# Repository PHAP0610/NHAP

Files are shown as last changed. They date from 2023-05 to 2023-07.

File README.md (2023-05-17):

# STM32F103

## Hardware BOARD V0.1

All file include and source in this: https://github.com/nguyentrungthao/STM32/tree/dev

### Module 7 segment with two ic 74595
1. Pin configuration.

<!-- cách ra 1 dòng để git hiểu là xuống hàng -->
<!-- :--- là căn trái :---: là căn giữa ---: là căn phải trong cột -->
| STM32 | 74595  | 
| :---: | :---: |
| PA4 | SER |
| PA5 | OE |
| PA6 | RCLK |
| PA7 | SRCLK |

2. Code 

high 8-bit to select a 7-segment digit 
low 8-bit is code-7-segment 
code7segment is used in this board sequence:
<!--  có nhiều fotmat khác như c, cpp, js, html,...... -->
```c
/* this code only use for this version board */
const char code7seg[] = {0xD7, 0x14, 0xCD, 0x5D, 0x1E, 0x5B, 0xDB, 0x15, 0xDF, 0x5F};
```
### Module rotary encoder 
1. Pin configuration 

| STM32 | Rotary Encoder | description | 
| :---: | :---: | :--- |
| PA8 | channel A | pull up |
| PA9 | channel B | pull up |
| PA10 | buttuon | pull up |

2. Code

PA8 - PA9 is encoder mode of timer1 
```c
/* Enable TIM1 encoder mode */
/* USER CODE BEGIN 2 */
HAL_TIM_Encoder_Start_IT(&htim1, TIM_CHANNEL_ALL);
/* USER CODE END 2 */

/* Get encoder value */
encoderValue = __HAL_TIM_GetCounter(&htim1);
```

### AC voltage control
1. Pin configuration 

| STM32 | Module | description |
| :---: | :---: | :--- |
| PB0 | AC Detec| pull up |
| PB1 | Triac |  |

2. code 

PB0 should be an EXT pin 
``` c
/* proccess when interrupt */
void HAL_GPIO_EXTI_Callback(uint16_t GPIO_Pin){
	if(GPIO_Pin == ACDET_Pin){
		SETFLAG(FLAG_ACDET_TRIGGER, flag);
        // control angle to set triac base on time which is calculated by PID
		__HAL_TIM_SET_COUNTER(&htim4, (uint16_t)(triac.giaTriDieuKhien * 1000));
//		__HAL_TIM_SET_COUNTER(&htim4, 9000);
	}
}
```

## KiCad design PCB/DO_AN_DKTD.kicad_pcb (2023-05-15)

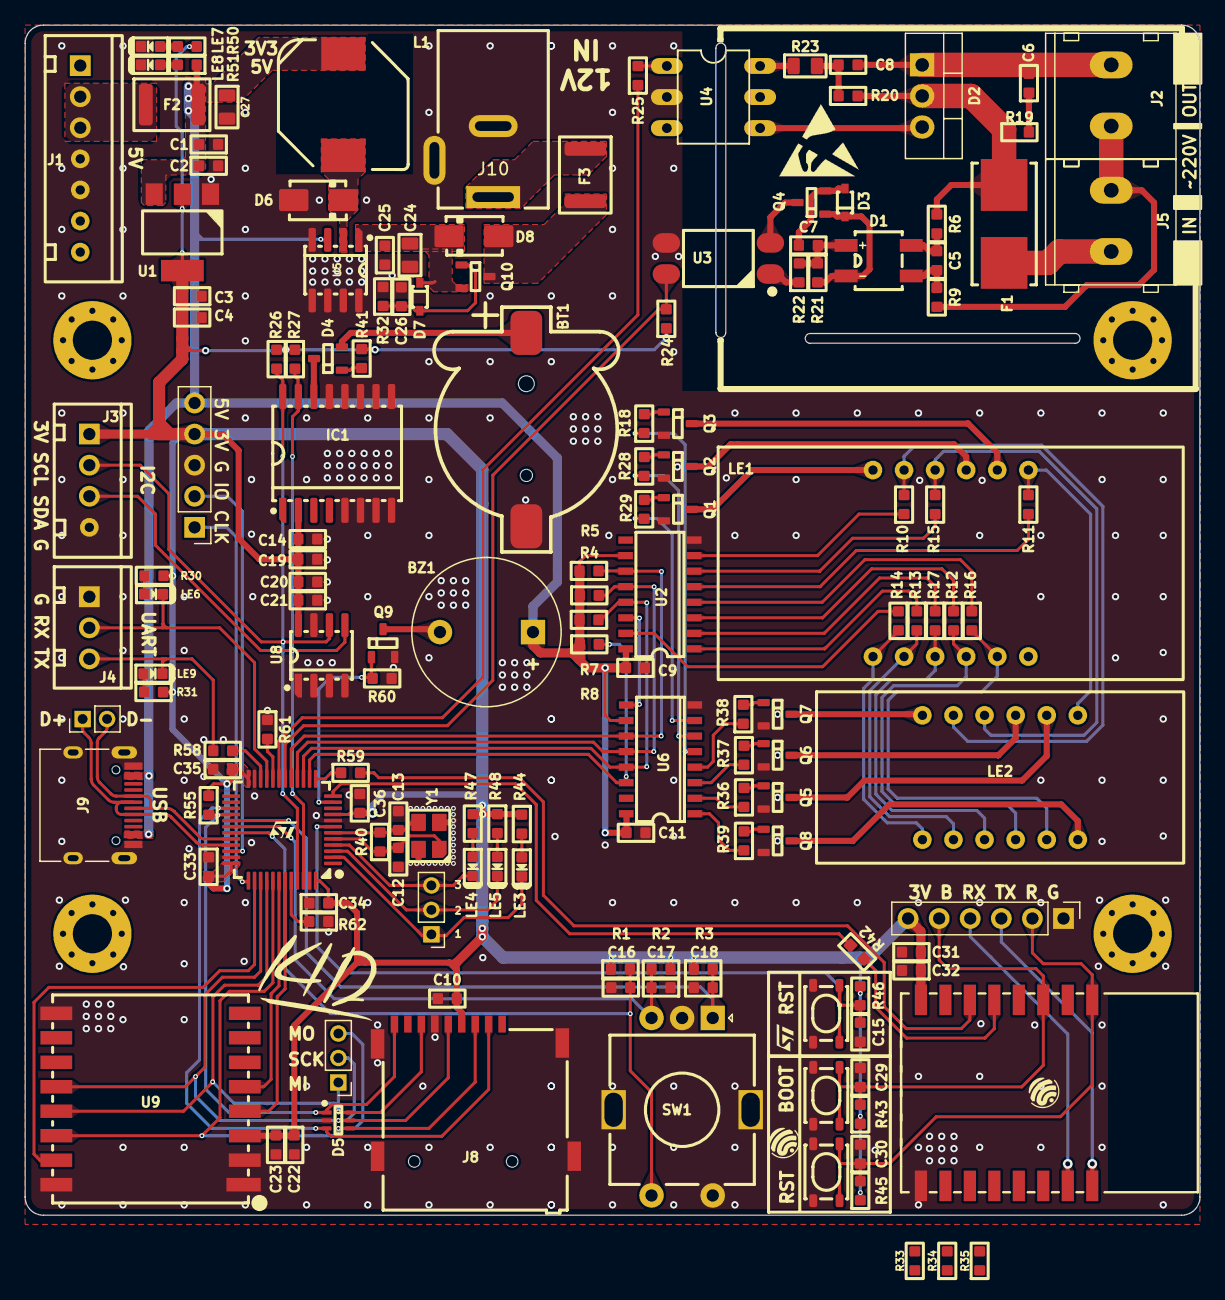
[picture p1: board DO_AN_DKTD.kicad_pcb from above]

Board: 2 copper layers, 96.0 x 97.2 mm, 153 parts (0 on the bottom side), 120 nets.

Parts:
BT1: CR1220; BatteryHolder_CR1220
BZ1: Buzzer; Buzzer_12x9.5RM7.6
C1, C3, C15, C16, C17, C18, C22, C25, C29, C30, C31: 1uF; C_0603
C2, C4, C9, C10, C11, C19, C21, C23, C26, C32, C33, C34, C35, C36: 100nF; C_0603
C5, C6: 10nF; C_0603
C7, C14, C20: 10uF; C_0603
C8: 50nF; C_0603
C12, C13: 22pF; C_0603
C24, C27: 10uF; C_0805
D1: MB10F; Bridge_MB10F-13
D2: TRIAC; TO-220-3_Vertical
D3: 1N4148; D_SOD323
D4: BAT54C; SOT23-3
D5: SMF05C; TSSOP-6
D6, D8: SS54; D_SMA
D7: D_Schottky; D_SOD323
F1: Fuse; Fuseholder_Littelfuse_Nano2_154x
F2, F3: Fuse; Fuse_1812_4532Metric
IC1: RTC_DS3231M; SOIC-16W_7.5x10.3mm_P1.27mm
J1: Conn_01x07; Conn_XH-P2.54mm-7P
J2, J5: Conn_01x02; KF128-5.0-2P
J3: Conn_01x04; Conn_XH-P2.54mm-4P
J4: Conn_01x03; Conn_XH-P2.54mm-3P
J6: PinHeader_1x06_P2.54mm_Vertical
J7: Conn_01x05_Male; PinHeader_1x05_P2.54mm_Vertical
J8: Micro_SD_Card_Det1; MicroSD_Socket_9P
J9: USB_C_Receptacle; USB_C_Receptacle_XKB_U262-16XN-4BVC11
J10: Jack-DC; BarrelJack_Wuerth_6941xx301002
J11, J12: Conn_01x03_Pin; PinHeader_1x03_P2.00mm_Vertical
J13: Conn_01x02_Pin; PinHeader_1x02_P2.00mm_Vertical
L1: 68uH 2A; L_10.4x10.4_H4.8
LE1: 5631AS; 7Segment_4led_CC_38x19
LE2: 5631AS; 7Segment_4led_Cathode_30x14mm
LE3, LE4, LE5, LE6, LE7, LE8, LE9: Led; LED_0603
Q1, Q2, Q3, Q4, Q5, Q6, Q7, Q8: NPN; SOT23-3
Q9: N_Mosfet; SOT23-3
Q10: P_Mosfet; SOT23-3
R1, R2, R3, R4, R5, R7, R8, R26, R27, R55: 4k7; R_0603
R6, R9: 180k; R_0603
R10, R11, R12, R13, R14, R15, R16, R17, R22, R24, R30, R31, R41, R44, R47, R48, R50, R51: 1k; R_0603
R18, R28, R29, R36, R37, R38, R39: 2k; R_0603
R19: 39; R_0603
R20: 470; R_0603
R21: 22k; R_0603
R23: 360; R_0805
R25: 360; R_0603
R32: 12k; R_0603
R33, R34, R35, R43, R45, R46: 10k; R_0603
R40, R60: 1M; R_0603
R42: 100; R_0603
R58, R59: 100R; R_0603
R61, R62: 10K; R_0603
SW1: RotaryEncoder_Switch; RotaryEncoder_Alps_EC11E-Switch_Vertical_H20mm
SW2, SW3, SW4: SW_Push; SW_SPST_PTS810
U1: AMS1117; SOT233
U2, U6: 74HC595; SOIC-16W_3.92x10.2mm
U3: PC817; OPTO_SOT254P975X400-4N
U4: MOC3020M; DIL06-E
U5: XL1509; SOIC-8_3.9x4.9mm_P1.27mm
U7: STM32F103C8Tx; LQFP-48_7x7mm_P0.5mm
U8: 24C32N; SOIC-8_3.9x4.9mm_P1.27mm
U9: Ai-Thinker-Ra-02; MODULE_RA-02_LORA
U10: ESP-07; ESP8266-07__ESP32-C3-12F
Y1: Crystal_GND24_Small; Crystal_3225_4P_3.2x2.6mm

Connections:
+3V3: C3.2, C4.1, C10.2, C14.2, C19.2, C20.2, C21.2, C22.1, C23.1, C31.1, C32.1, C33.2, C34.2, C35.2, C36.2, IC1.2 (VCC), J3.1, J6.6, J7.4, J8.4 (VDD), R1.1, R2.1, R3.1, R24.1, R26.1, R27.1, R30.1, R31.1, R33.2, R34.2, R41.1, R43.1, R44.1, R45.1, R46.1, R47.1, R48.1, R50.1, R55.1, U1.2 (VO), U7.9 (VDDA), U7.24 (VDD), U7.36 (VDD), U7.48 (VDD), U8.8 (VCC), U9.3 (VDD), U10.8 (VCC)
+5V: BZ1.1 (-), C1.2, C2.1, C9.2, C11.2, C27.1, F2.2, J7.5, J9.A4 (VBUS), J9.A9 (VBUS), J9.B4 (VBUS), J9.B9 (VBUS), L1.2, R4.1, R5.1, R7.1, R8.1, R51.1, U1.3 (VI), U2.10 (~SRCLR), U2.16 (VCC), U5.3 (FB), U6.10 (~SRCLR), U6.16 (VCC)
/ESP/BOOT: C29.1, J6.5, R43.2, SW3.2, U10.18 (GPIO0)
/ESP/RST: C30.1, J6.2, R45.2, SW2.2, U10.1 (~RST)
/ESP/RX: J6.4, U10.21 (GPIO3/RXD)
/ESP/RX_ESP32: R42.2, U7.12 (PA2)
/ESP/TX: J6.3, U10.22 (GPIO1/TXD)
/ESP/TX_ESP32: R59.2, U10.6 (GPIO12)
/POWER/5vin: F2.1, J1.2, J1.3
/POWER/A: F3.1, J10.1
/POWER/B: D8.1, F3.2, Q10.3 (D)
/POWER/VOUT: D6.2, L1.1, U5.2 (OUTPUT)
/Peripheral/24C32.SCL: IC1.16 (SCL), J3.2, R26.2, U7.45 (PB8), U8.6 (SCL)
/Peripheral/24C32.SDA: IC1.15 (SDA), J3.3, R27.2, U7.46 (PB9), U8.5 (SDA)
/Peripheral/74HC595.OE: R7.2, U2.13 (~OE), U6.13 (~OE), U7.15 (PA5)
/Peripheral/74HC595.RCLK: R4.2, U2.12 (RCLK), U6.12 (RCLK), U7.16 (PA6)
/Peripheral/74HC595.SER: R8.2, U6.14 (SER), U7.14 (PA4)
/Peripheral/74HC595.SRCLK: R5.2, U2.11 (SRCLK), U6.11 (SRCLK), U7.17 (PA7)
/Peripheral/AC_DET: R24.2, U3.4, U7.18 (PB0)
/Peripheral/Buzzer: Q9.1 (G), R60.1, U7.11 (PA1)
/Peripheral/Encoder.EnC_A: C18.2, R3.2, SW1.A, U7.29 (PA8)
/Peripheral/Encoder.EnC_B: C17.2, R2.2, SW1.B, U7.30 (PA9)
/Peripheral/Encoder.EnC_BT: C16.2, R1.2, SW1.S1, U7.31 (PA10)
/Peripheral/L: F1.2, J5.1
/Peripheral/LE1: R29.1, U6.7 (QH)
/Peripheral/LE2: R28.1, U6.6 (QG)
/Peripheral/LE3: R18.1, U6.5 (QF)
/Peripheral/LE4: R38.1, U6.4 (QE)
/Peripheral/LE5: R37.1, U6.3 (QD)
/Peripheral/LE6: R36.1, U6.2 (QC)
/Peripheral/LE7: R39.1, U6.1 (QB)
/Peripheral/LOG_RX: J4.2, LE6.2, U7.21 (PB10)
/Peripheral/LOG_TX: J4.3, LE9.2, R58.1
/Peripheral/LORA.CS: U7.38 (PA15), U9.15 (~NSS)
/Peripheral/LORA.INT: U7.42 (PB6), U9.5 (DIO0)
/Peripheral/LORA.MISO: D5.6, J8.7 (DAT0), J12.1, U7.40 (PB4), U9.13 (MISO)
/Peripheral/LORA.MOSI: D5.4, J8.3 (CMD), J12.3, U7.41 (PB5), U9.14 (MOSI)
/Peripheral/LORA.RST: U7.43 (PB7), U9.4 (~RESET)
/Peripheral/LORA.SCK: D5.5, J8.5 (CLK), J12.2, U7.39 (PB3), U9.12 (SCK)
/Peripheral/L_after: D2.2 (A2), F1.1, R6.2, R19.1, R20.2
/Peripheral/Load: C6.2, C8.2, D2.1 (A1), J2.2
/Peripheral/N: J2.1, J5.2, R9.2
/Peripheral/SD.CS: D5.3, J8.2 (DAT3/CD), U7.27 (PB14)
/Peripheral/SD.DET: D5.1, J8.9 (DET), R55.2, U7.28 (PB15)
/Peripheral/TRIAC: R25.1, U7.19 (PB1)
/Peripheral/TYPE_C.D+: J9.A6 (D+), J9.B6 (D+), J13.1, U7.33 (PA12)
/Peripheral/TYPE_C.D-: J9.A7 (D-), J9.B7 (D-), J13.2, U7.32 (PA11)
/Peripheral/Vbat: BT1.1 (+), D4.2
/STM32/Led_test1: J11.1, LE3.2, U7.2 (PC13)
/STM32/Led_test2: J11.2, LE5.2, U7.3 (PC14)
/STM32/Led_test3: J11.3, LE4.2, U7.4 (PC15)
/STM32/PD0: C12.2, R40.1, U7.5 (PD0), Y1.1
/STM32/PD1: C13.1, R40.2, U7.6 (PD1), Y1.3
/STM32/RST: C15.1, R46.2, SW4.2, U7.7 (NRST)
/STM32/SWCLK: J7.1, U7.37 (PA14)
/STM32/SWDIO: J7.2, U7.34 (PA13)
GND: BT1.2 (-), C1.1, C2.2, C3.1, C4.2, C9.1, C10.1, C11.1, C12.1, C13.2, C14.1, C15.2, C16.1, C17.1, C18.1, C19.1, C20.1, C21.1, C22.2, C23.2, C24.2, C25.1, C26.2, C27.2, C29.2, C30.2, C31.2, C32.2, C33.1, C34.1, C35.1, C36.1, D5.2, D6.1, IC1.5 (GND), IC1.6 (GND), IC1.7 (GND), IC1.8 (GND), IC1.9 (GND), IC1.10 (GND), IC1.11 (GND), IC1.12 (GND), IC1.13 (GND), J1.4, J1.5, J3.4, J4.1, J6.1, J7.3, J8.6 (VSS), J8.10 (SHIELD), J9.A1 (GND), J9.A12 (GND), J9.B1 (GND), J9.B12 (GND), J9.S1 (SHIELD), J10.2, LE7.2, LE8.2, Q1.2 (E), Q2.2 (E), Q3.2 (E), Q5.2 (E), Q6.2 (E), Q7.2 (E), Q8.2 (E), Q9.2 (S), R32.2, R35.1, R60.2, R61.1, R62.1, SW1.C, SW1.MP (Shield), SW1.S2, SW2.1, SW3.1, SW4.1, U1.1 (GND), U2.8 (GND), U3.3, U4.2, U5.4 (ON/OFF), U5.5 (GND), U5.6 (GND), U5.7 (GND), U5.8 (GND), U6.8 (GND), U7.8 (VSSA), U7.23 (VSS), U7.35 (VSS), U7.47 (VSS), U8.1 (A0), U8.2 (A1), U8.3 (A2), U8.4 (GND), U8.7 (WP), U9.1 (GND), U9.2 (GND), U9.9 (GND), U9.16 (GND), U10.15 (GND), Y1.2, Y1.4
unnamed: D4.3, IC1.14 (VBAT)
unnamed: BZ1.2 (+), Q9.3 (D)
unnamed: C5.1, D1.4, R6.1
unnamed: C5.2, D1.2, R9.1
unnamed: C6.1, R19.2
unnamed: C8.1, R20.1, R23.2
unnamed: C7.1, D1.1 (+), R21.1, R22.2
unnamed: D1.3 (-), D3.2, Q4.1 (B), R21.2
unnamed: D2.3 (G), U4.4
unnamed: D4.1, R41.2
unnamed: LE1.12 (CC1), Q1.3 (C)
unnamed: LE1.9 (CC2), Q2.3 (C)
unnamed: LE1.8 (CC3), Q3.3 (C)
unnamed: LE1.3 (DPX), LE2.3 (DPX), R17.2
unnamed: LE1.11 (a), LE2.11 (a), R10.2
unnamed: LE1.7 (b), LE2.7 (b), R11.2
unnamed: LE1.4 (c), LE2.4 (c), R12.2
unnamed: LE1.2 (d), LE2.2 (d), R13.2
unnamed: LE1.1 (e), LE2.1 (e), R14.2
unnamed: LE1.10 (f), LE2.10 (f), R15.2
unnamed: LE1.5 (g), LE2.5 (g), R16.2
unnamed: LE2.12 (CC1), Q7.3 (C)
unnamed: LE2.9 (CC2), Q6.3 (C)
unnamed: LE2.8 (CC3), Q5.3 (C)
unnamed: LE2.6 (CC4), Q8.3 (C)
unnamed: LE3.1, R44.2
unnamed: LE4.1, R47.2
unnamed: LE5.1, R48.2
unnamed: LE6.1, R30.2
unnamed: LE7.1, R50.2
unnamed: LE8.1, R51.2
unnamed: LE9.1, R31.2
unnamed: Q1.1 (B), R29.2
unnamed: Q2.1 (B), R28.2
unnamed: Q3.1 (B), R18.2
unnamed: Q4.3 (C), U3.2
unnamed: C7.2, D3.1, Q4.2 (E)
unnamed: Q5.1 (B), R36.2
unnamed: Q6.1 (B), R37.2
unnamed: Q7.1 (B), R38.2
unnamed: Q8.1 (B), R39.2
unnamed: C26.1, D7.1, Q10.1 (G), R32.1
unnamed: R22.1, U3.1
unnamed: R23.1, U4.6
unnamed: R25.2, U4.1
unnamed: R14.1, U2.15 (QA)
unnamed: R13.1, U2.1 (QB)
unnamed: R17.1, U2.2 (QC)
unnamed: R12.1, U2.3 (QD)
unnamed: R16.1, U2.4 (QE)
unnamed: R11.1, U2.5 (QF)
unnamed: R15.1, U2.6 (QG)
unnamed: R10.1, U2.7 (QH)
unnamed: U2.14 (SER), U6.9 (QH')
unnamed: R62.2, U7.44 (BOOT0)
unnamed: R59.1, U7.13 (PA3)
unnamed: R61.2, U7.20 (PB2)
unnamed: R58.2, U7.22 (PB11)
unnamed: R33.1, U10.3 (EN)
unnamed: R34.1, U10.17 (GPIO2)
unnamed: R42.1, U10.5 (GPIO14)
unnamed: R35.2, U10.16 (GPIO15)
VDC: C24.1, C25.2, D7.2, D8.2, Q10.2 (S), U5.1 (VIN)

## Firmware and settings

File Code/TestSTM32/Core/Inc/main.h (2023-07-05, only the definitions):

#define LE4_Pin GPIO_PIN_13
#define LE4_GPIO_Port GPIOC
#define LE5_Pin GPIO_PIN_14
#define LE5_GPIO_Port GPIOC
#define LE3_Pin GPIO_PIN_15
#define LE3_GPIO_Port GPIOC
#define BUZZER_Pin GPIO_PIN_1
#define BUZZER_GPIO_Port GPIOA
#define HC595_DS_Pin GPIO_PIN_4
#define HC595_DS_GPIO_Port GPIOA
#define HC595_OE_Pin GPIO_PIN_5
#define HC595_OE_GPIO_Port GPIOA
#define HC595_LATCH_Pin GPIO_PIN_6
#define HC595_LATCH_GPIO_Port GPIOA
#define HC595_SCLK_Pin GPIO_PIN_7
#define HC595_SCLK_GPIO_Port GPIOA
#define ACDET_Pin GPIO_PIN_0
#define ACDET_GPIO_Port GPIOB
#define TRIAC_Pin GPIO_PIN_1
#define TRIAC_GPIO_Port GPIOB
#define EnA_Pin GPIO_PIN_8
#define EnA_GPIO_Port GPIOA
#define EnB_Pin GPIO_PIN_9
#define EnB_GPIO_Port GPIOA
#define EnBtn_Pin GPIO_PIN_10
#define EnBtn_GPIO_Port GPIOA

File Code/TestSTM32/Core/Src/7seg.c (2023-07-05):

/*
 * 7seg.c
 *
 *  Created on: Jul 5, 2023
 *      Author: KHOA
 */


#include "7seg.h"
const char code7seg[] = {0xD7, 0x14, 0xCD, 0x5D, 0x1E, 0x5B, 0xDB, 0x15, 0xDF, 0x5F};

void SegLed_TestAllOutput()
{
	HAL_GPIO_WritePin(HC595_LATCH_GPIO_Port, HC595_LATCH_Pin, 0);
	HAL_GPIO_WritePin(HC595_DS_GPIO_Port, HC595_DS_Pin, 1);
	for(uint8_t i = 0; i < 16;i++){
		HAL_GPIO_WritePin(HC595_SCLK_GPIO_Port, HC595_SCLK_Pin, 1);
		HAL_GPIO_WritePin(HC595_SCLK_GPIO_Port, HC595_SCLK_Pin, 0);
	}
	HAL_GPIO_WritePin(HC595_LATCH_GPIO_Port, HC595_LATCH_Pin, 1);
	HAL_GPIO_WritePin(HC595_LATCH_GPIO_Port, HC595_LATCH_Pin, 0);
}

void SegLed_OutputDigit()
{
	uint16_t testDigit = 0x01ff;
	for(uint8_t i = 0; i < 16;i++){
		if((testDigit&0x01) == 1) HAL_GPIO_WritePin(HC595_DS_GPIO_Port, HC595_DS_Pin, 1);
		else HAL_GPIO_WritePin(HC595_DS_GPIO_Port, HC595_DS_Pin, 0);
		HAL_GPIO_WritePin(HC595_SCLK_GPIO_Port, HC595_SCLK_Pin, 1);
		HAL_GPIO_WritePin(HC595_SCLK_GPIO_Port, HC595_SCLK_Pin, 0);
		testDigit = (testDigit >> 1);
	}
	HAL_GPIO_WritePin(HC595_LATCH_GPIO_Port, HC595_LATCH_Pin, 1);
	HAL_GPIO_WritePin(HC595_LATCH_GPIO_Port, HC595_LATCH_Pin, 0);
}

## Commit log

2023-05-15 init git, .gitignore, README.md and copy file from project 1
    [DO_AN_DKTD.kicad_pcb, DO_AN_DKTD.kicad_sch, ESP.kicad_sch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]
2023-05-15 update README discription board
2023-05-17 init new project to clear code, update link LIB STM32

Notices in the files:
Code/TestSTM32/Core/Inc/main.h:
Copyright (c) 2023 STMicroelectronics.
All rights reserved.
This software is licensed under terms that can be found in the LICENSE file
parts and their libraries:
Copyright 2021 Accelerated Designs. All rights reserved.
